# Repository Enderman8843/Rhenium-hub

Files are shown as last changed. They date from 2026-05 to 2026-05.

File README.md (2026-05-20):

# Rhenium HUB
It is Hi-Speed USB HUB with USB2514B_B Chip and 24mhz crystal , With Support of USB C aswell as USB A

## How To Use ?
JUST PlUG IT INTO YOUR COMPUTER VIA THE INPUT

## PCB Layout and Render

| PCB | Schematics / Wiring |
|---|---|
| 
 |
|

| 3D View Rear | |
|---|---|


| Case | 


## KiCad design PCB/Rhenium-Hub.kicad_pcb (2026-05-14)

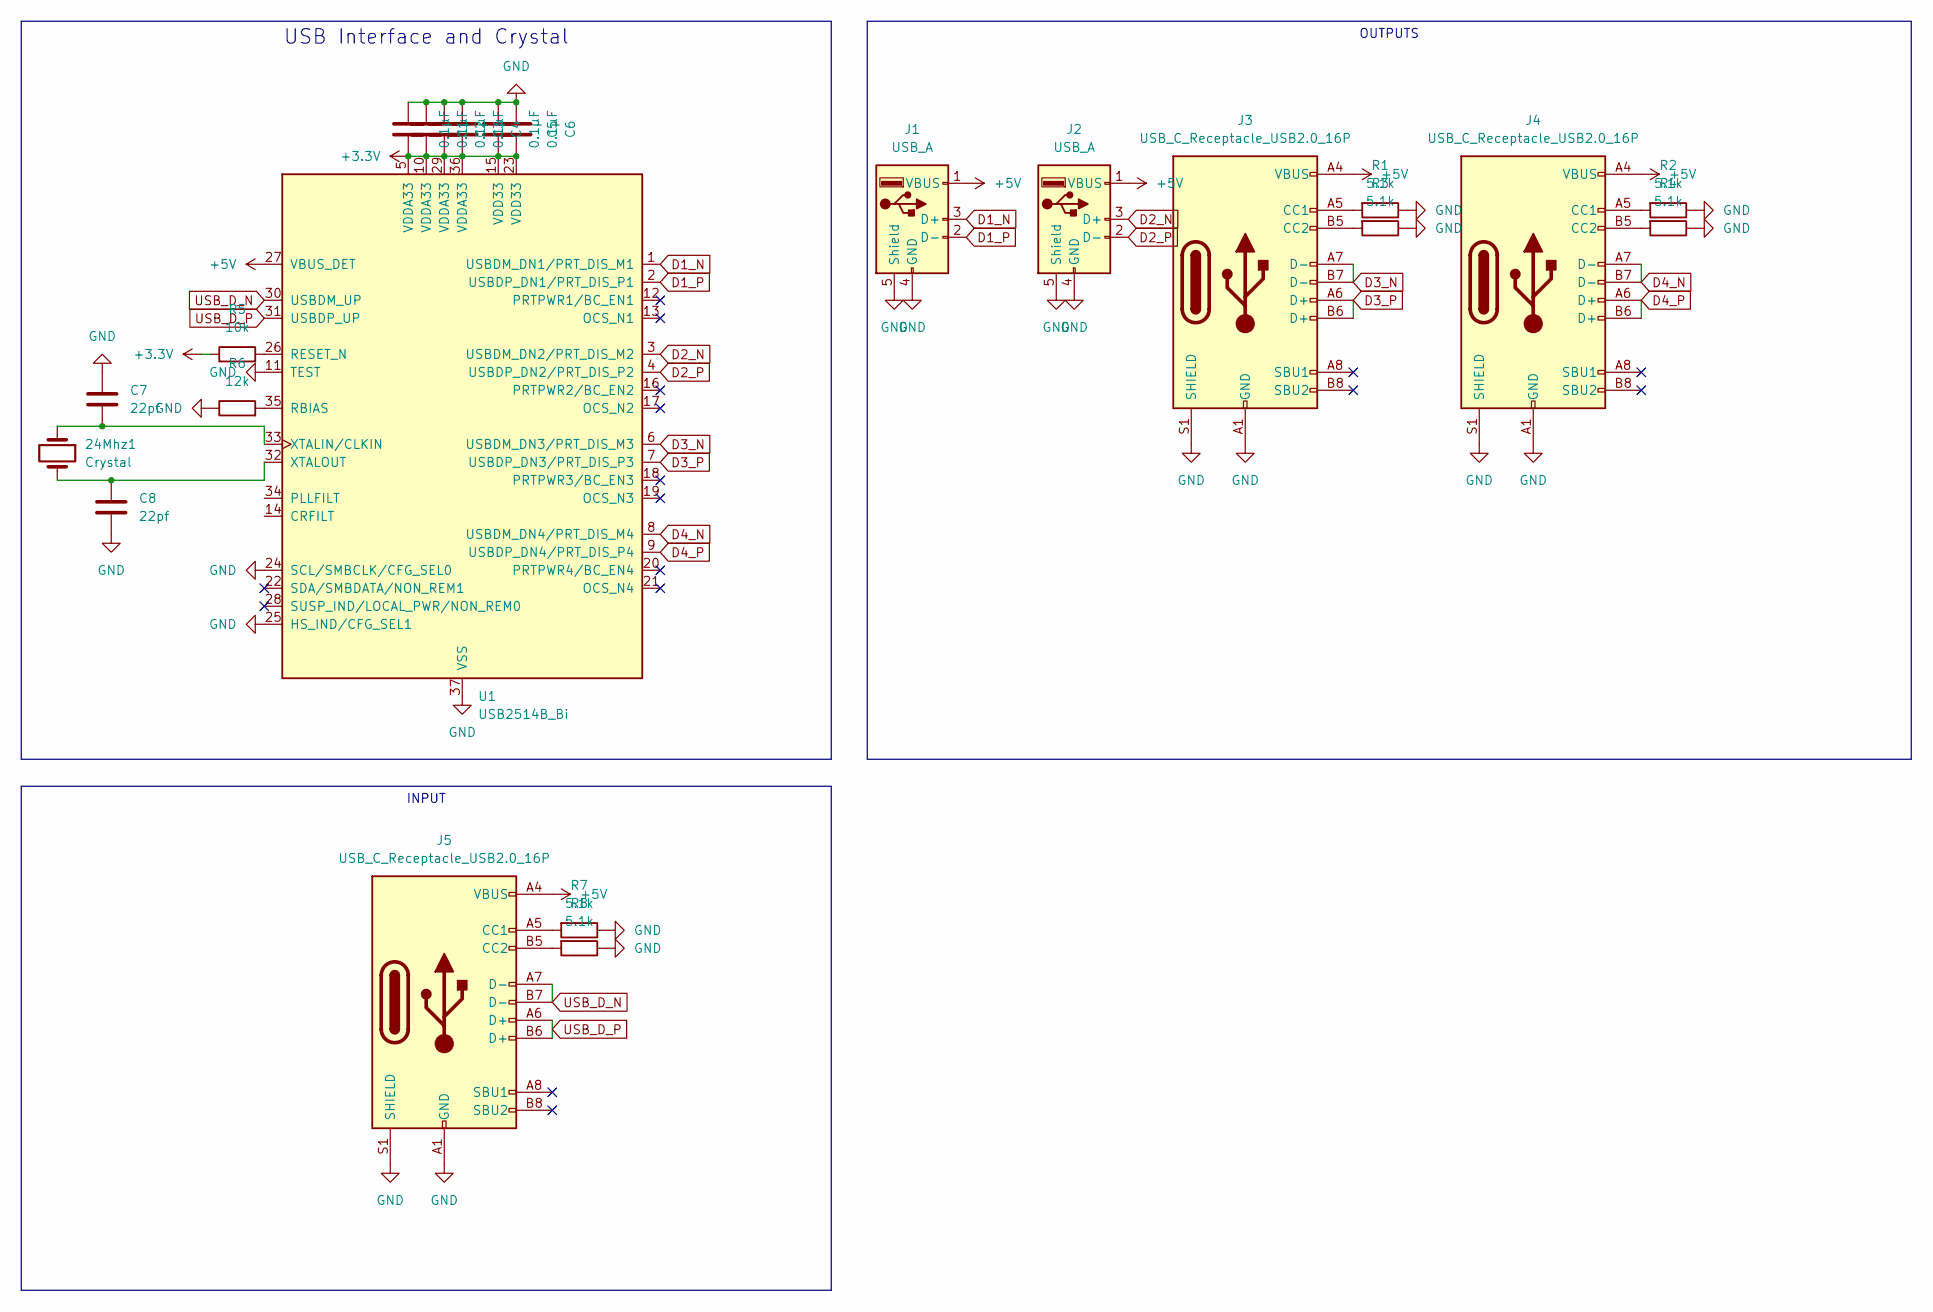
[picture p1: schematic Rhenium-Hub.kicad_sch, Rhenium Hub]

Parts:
24Mhz1: Crystal; Crystal_SMD_3225-4Pin_3.2x2.5mm
C1, C2, C3, C4, C5, C6: 0.1µF; C_0603_1608Metric
C7, C8: 22pf; C_0603_1608Metric
J1, J2: USB_A; USB_A_CNCTech_1001-011-01101_Horizontal
J3, J4, J5: USB_C_Receptacle_USB2.0_16P; USB_C_Receptacle_G-Switch_GT-USB-7010ASV
R1, R2, R3, R4, R7, R8: 5.1k; C_0603_1608Metric
R5: 10k; C_0603_1608Metric
R6: 12k; C_0603_1608Metric
U1: USB2514B_Bi; QFN-36-1EP_6x6mm_P0.5mm_EP3.7x3.7mm

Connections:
+3.3V: C1.2, C2.2, C3.2, C4.2, C5.2, C6.2, R5.1, U1.5 (VDDA33), U1.10 (VDDA33), U1.15 (VDD33), U1.23 (VDD33), U1.29 (VDDA33), U1.36 (VDDA33)
+5V: J1.1 (VBUS), J2.1 (VBUS), J3.A4 (VBUS), J3.A9 (VBUS), J3.B4 (VBUS), J3.B9 (VBUS), J4.A4 (VBUS), J4.A9 (VBUS), J4.B4 (VBUS), J4.B9 (VBUS), J5.A4 (VBUS), J5.A9 (VBUS), J5.B4 (VBUS), J5.B9 (VBUS), U1.27 (VBUS_DET)
D1_N: J1.3 (D+), U1.1 (USBDM_DN1/PRT_DIS_M1)
D1_P: J1.2 (D-), U1.2 (USBDP_DN1/PRT_DIS_P1)
D2_N: J2.3 (D+), U1.3 (USBDM_DN2/PRT_DIS_M2)
D2_P: J2.2 (D-), U1.4 (USBDP_DN2/PRT_DIS_P2)
D3_N: J3.A7 (D-), J3.B7 (D-), U1.6 (USBDM_DN3/PRT_DIS_M3)
D3_P: J3.A6 (D+), J3.B6 (D+), U1.7 (USBDP_DN3/PRT_DIS_P3)
D4_N: J4.A7 (D-), J4.B7 (D-), U1.8 (USBDM_DN4/PRT_DIS_M4)
D4_P: J4.A6 (D+), J4.B6 (D+), U1.9 (USBDP_DN4/PRT_DIS_P4)
GND: C1.1, C2.1, C3.1, C4.1, C5.1, C6.1, C7.1, C8.2, J1.4 (GND), J1.5 (Shield), J2.4 (GND), J2.5 (Shield), J3.A1 (GND), J3.A12 (GND), J3.B1 (GND), J3.B12 (GND), J3.S1 (SHIELD), J4.A1 (GND), J4.A12 (GND), J4.B1 (GND), J4.B12 (GND), J4.S1 (SHIELD), J5.A1 (GND), J5.A12 (GND), J5.B1 (GND), J5.B12 (GND), J5.S1 (SHIELD), R1.1, R2.1, R3.1, R4.1, R6.1, R7.1, R8.1, U1.11 (TEST), U1.24 (SCL/SMBCLK/CFG_SEL0), U1.25 (HS_IND/CFG_SEL1), U1.37 (VSS)
unnamed: J3.A5 (CC1), R1.2
unnamed: J3.B5 (CC2), R3.2
unnamed: J4.A5 (CC1), R2.2
unnamed: J4.B5 (CC2), R4.2
unnamed: J5.A5 (CC1), R7.2
unnamed: J5.B5 (CC2), R8.2
unnamed: R6.2, U1.35 (RBIAS)
unnamed: R5.2, U1.26 (RESET_N)
unnamed: 24Mhz1.1, C7.2, U1.33 (XTALIN/CLKIN)
unnamed: 24Mhz1.2, C8.1, U1.32 (XTALOUT)
USB_D_N: J5.A7 (D-), J5.B7 (D-), U1.30 (USBDM_UP)
USB_D_P: J5.A6 (D+), J5.B6 (D+), U1.31 (USBDP_UP)

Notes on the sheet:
INPUT
USB Interface and Crystal
OUTPUTS

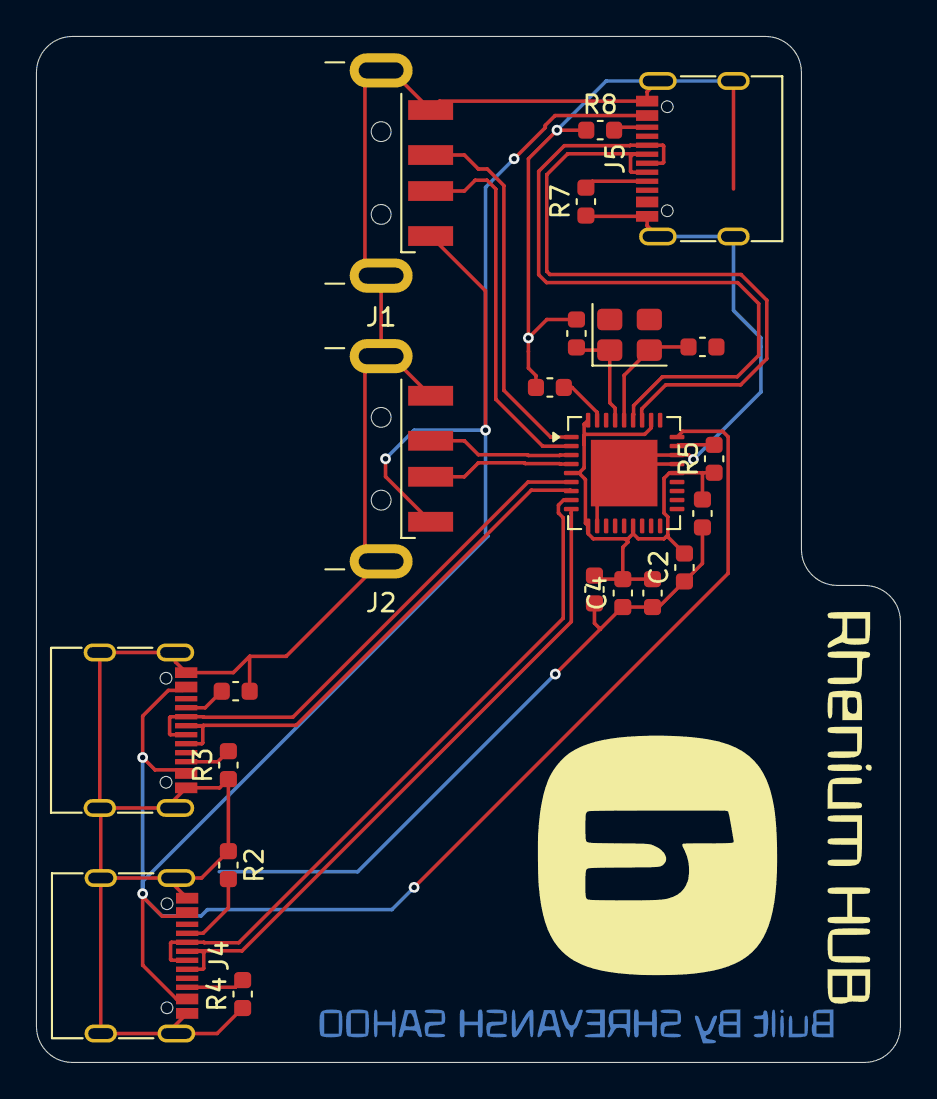
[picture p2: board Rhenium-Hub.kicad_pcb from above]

Board: 2 copper layers, 48.0 x 57.0 mm, 22 parts (0 on the bottom side), 23 nets.
